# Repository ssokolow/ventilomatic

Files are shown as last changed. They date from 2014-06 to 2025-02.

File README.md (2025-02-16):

# Ventilomatic

A mixture of "course project" and "prototype of a hobby project" intended to
log and regulate the temperature, light level, and humidity in my bedroom.

See the [project site](http://ssokolow.github.io/ventilomatic) for more
details.

## Requirements

* Linux (not yet tested for portability)
* Python 2.x (Python 3.x support will come later)
* [pySerial](http://pyserial.sourceforge.net/) (Will be made optional later)
* [Weatherpy](https://github.com/cmcdowell/weatherpy) (Will be made optional
  later)
* [BottleRocket](http://www.linuxha.com/bottlerocket/) (For X10 control)
* [`libnotify`](http://www.galago-project.org/news/index.php) (For `notify-send`)

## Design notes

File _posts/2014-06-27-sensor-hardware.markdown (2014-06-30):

---
layout: post
title:  "Sensor Hardware"
date:   2014-06-27 01:20:00
categories: design hardware
---

Sorry for the wait (life got **very** distracting and stressful), but here we are. The sensor nodes are done and the Fritzing schematic is in the repository.

**Update:** Incomplete documentation led me to incorrectly believe Pin 10 was free when using the Arduino Ethernet shield. I've relocated the buzzer to pin 8 and updated both the photos and Fritzing files. The originals are available via the git history.

Here are the three different prototype sensor designs:

Arduino Uno + Ethernet Shield
Arduino Leonardo + EtherCard
Sparkfun RedBoard

They all look quite different but, aside from the method of communication (Ethernet shield, EtherCard, and USB serial), they all follow this exact same schematic (Fritzing source files available in the repository, though the non-Breadboard views are a bit of a mess because the DHT22 part for Fritzing is a bit broken):

Fritzing Breadboard View

Sorry about how messy it is. I'm too short on time to find a better way to populate the breadboard and that's the most useful of several ugly options for laying out the Fritzing render.

I haven't yet written the network code, but the draft code for version 1 of the serial interaction model is done (and streams line-by-line JSON in this format):

```json
{ "api_version": 0, "humidity": 56.20, "temperature": 25.10, "dewpoint": 16.34, "light": 295.00 }
```

**Update:** See [Sensing Is A Go]({{ site.baseurl}}{% post_url 2014-06-29-sensing-is-a-go %}) for the updated form the JSON messages take.

Two tips for working on this sort of project:

1. Work with familiar hardware. I don't know what it was, but the Redboard was giving me trouble at first and it was a lot easier to iron out the design and code on my old reliable Arduino Uno (the tallest node pictured), then assemble the design on the Redboard once I was sure that any issues wouldn't be software bugs.
2. Make sure you remember to unplug any other Arduinos before programming. My Uno uses a USB A-B cable while my Leonardo and Redboard use USB A-MiniB and, for a few minutes, I was very frustrated when the serial monitor output wasn't showing changes I'd made to how the board was wired up. Turns out, I was monitoring the wrong Arduino.

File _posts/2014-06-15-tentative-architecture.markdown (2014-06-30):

---
layout: post
title:  "Tentative Architecture"
date:   2014-06-15 08:24:42
categories: design software
---

Here is my first draft for how information will flow in the system's network-transparent design.
(I'll fix the bad kerning once I have a build scripting system in place to make
use of the more complicated commands needed.)

**Update:** At present, due to time constraints, I've had to go for **push-based design** with raw **newline-terminated JSON packets over UDP**. I still hope to switch to a pull-based HTTP design in the future.

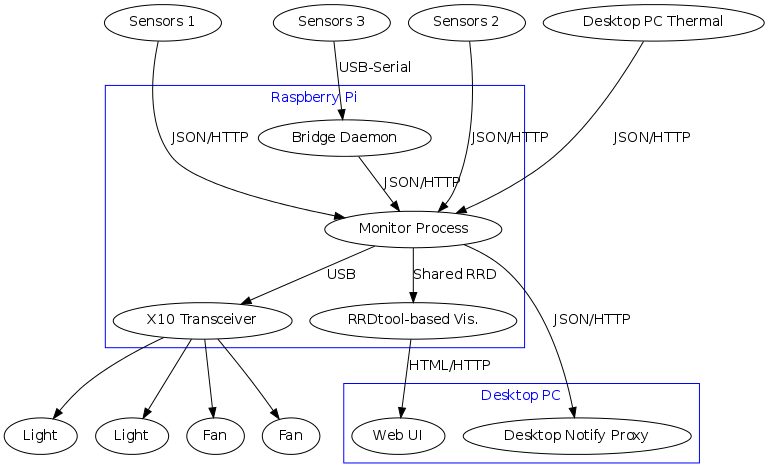
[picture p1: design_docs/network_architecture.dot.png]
Graph Diagram

[[source]({{ site.baseurl}}/design_docs/network_architecture.dot)]

I'm not yet 100% certain that I will use HTTP as the transport for the sensors instead
of UDP but, as the Pythonistas say, premature optimization is the root of all
evil and I definitely want to have JSON-over-HTTP as an option for receiving
sensor data from full-fledged Linux devices.

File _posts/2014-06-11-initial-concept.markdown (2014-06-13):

---
layout: post
title:  "Initial Plans"
date:   2014-06-11 05:43:31
categories: design
---

Well, let's get this project started. This has two purposes:

1. First, it's my course project for [COMP444: Embedded/Robotic Programming](http://www.athabascau.ca/syllabi/comp/comp444.php).

2. More satisfyingly, it's also a chance to prototype a mixture of two
or three ideas that have been rattling around my head and notebook for a while
now.

   Basically, a mixture of an analytics system and pseudo-HVAC controller for
   the temperature, humidity, and light levels in my bedroom.

As I don't yet have the skills to truly produce the design I consider suitable
for permanent installation, this will still have a ways to go, but it should
replicate the function, if not the form, that I desire.

For records purposes, here is the napkin outline I'll be starting from as a
direct quote from the e-mail in which I sent it:

```
1.1. Connect my Arduino Uno, Ethernet Shield, a CdS photoresistor, and
     a "wall wart" power brick.
1.2. Write a simple sketch which allows the sensor to be queried via
     the LAN.
1.3. Attach the photoresistor to the window.

2.1. Connect my Arduino Leonardo, Ethernet Module, a DHT11
     temperature/humidity sensor, and a "wall wart" power brick.
2.2. Again, simple sketch to allow LAN query
2.3. Place the temperature sensor in the family room

3.1. Plug a USB X10 transmitter and Arduino Nano into my Raspberry Pi
3.2. Connect a CdS cell and DHT11 to the Arduino
3.3. Screw my (ugly scrap) alarm system door sensor onto my door frame
     and connect it to the Arduino Nano.
3.3. Write a simple sketch which sends reports to the Raspberry Pi via
     USB serial
3.4. Place the assembly on my desk where it can get a decent
     "baseline room average" reading

4.1. Write a cronjob on the Pi to retrieve sunrise and sunset times and
     exterior temperature and humidity from Yahoo! Weather.
4.2. Write some Python code on the Pi to query and collate all of the
     sensor and Yahoo! weather data and use it for both rrdtool graphs
     and a simple automated light and air quality controller.

Controller goals:
1. Turn the lights off when the sunlight becomes bright enough to
   provide equivalent illumination.
2. Turn the [two independently controlled] fans on and off to control
   humidity in the corner and to exhaust hot summer air into the rest
   of the basement to maintain temperature.
3. If the door is closed, notify the user to open it when air
   circulation is necessary.
4. If the weather forecast says the outdoor air should be a more
   desirable temperature/humidity than the air in the family room,
   notify the user to open the window.
5. If the computer is still in use when the room lighting drops below
   a specified level, turn on a suitable bias light.

(My X10 system already allows me manual control over three light sources,
two fans, a door chime, and an X10 universal module (remote 30V DC relay
and/or sounder, continuous or momentary) which I have yet to find a use for.)

Stretch Goals:
5.1. Write a tool on my desktop PC which feeds in the screensaver
     subsystem's idleness data for information about
     user presence and activity to inform decision-making.
5.2. Extend the tool to listen to output from the "motion" utility
     to detect user presence when away from keyboard via the webcam.
```

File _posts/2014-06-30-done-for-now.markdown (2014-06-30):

---
layout: post
title:  "Done (For Now)"
date:   2014-06-30 03:45:00
categories: status
---
I have some stuff to finish up in another course, so I seriously doubt I'll be able to work on this any more before the end of today. As such, this is the final state the project will take before my course deadline.

# Results

Given the time-crunch, I definitely had to make some compromises. (For example, I'm currently running the control node on my desktop PC because it already has the CM17A set up for sending X10 messages but I used that as a blocking operation. While fast reactions may not be essential in this application, I'll still want to switch to an asynchronous design if for no other reason than making absolutely sure it's impossible for the UDP receive buffers to overflow and start losing measurements I want to log and graph.)

I also noticed that the voltage regulator on my Arduino Uno is dissipating a lot more heat than would seem reasonable when powered by [my 9V supply]({{ site.baseurl }}/img/parts/psu_2.jpg) so that's something else I'll have to investigate before producing versions for permanent installation.

However, given my goals, the obstacles I faced, and the time I had, I think I did pretty well for a first sprint. Here is an overview of the status of the "end result" goals as of my course's contract date:

### Controller Goal #1: DONE
*Turn the lights off when the sunlight becomes bright enough to
   provide equivalent illumination.*

I don't have time to properly calibrate it before my contract date, but the light sensor on the `corner` node (the one on an extension and taped to the window) will currently trigger a shut-down of all three X10-controllable lights in the room when it detects a high enough reading.

All I have to do is open the window, reach out with my high-intensity LED flashlight, and `*CLACK* ... *CLACK* ... *CLACK*`, all of the X10-controllable lights in the room turn off.

### Controller Goal #2: PARTIAL
*Turn the [two independently controlled] fans on and off to control humidity in the corner and to exhaust hot summer air into the rest of the basement to maintain temperature.*

I've implemented the rule for dealing with humidity in the corner, but the temperature part requires a sensor outside my room and I didn't have time to get the EtherCard stuff written and debugged.

### Controller Goal #3: FOILED
*If the door is closed, notify the user to open it when circulation is necessary.*

I looked everywhere and can't figure out where I stashed my magnetic reed switch. I've ordered a new five-pack, but they won't be here before my contract date. However, I *can* write master controller code for when the hardware *does* get added to one of the sensor nodes and I can write it in such a way that it assumed a missing sensor means "door closed" so it'll always ask me.

### Controller Goal #4: DONE
*If the weather forecast says the outdoor air should be a more desirable temperature/humidity than the air in the family room, notify the user to open the window.*

The system queries Yahoo! Weather once an hour to get the outside temperature and, if the desired temperature is closer to that than the indoor air temperature, it uses `notify-send` to suggest opening a window.

### Controller Goal #5: MISSED
*If the computer is still in use when the room lighting drops below a specified level, turn on a suitable bias light.*

I ran out of time before I could write the daemon to feed readings from the screensaver's idleness API into the system. As such, it has no way to detect "If the computer is still in use when..."

I'll try to make time to write this within the first week of July.

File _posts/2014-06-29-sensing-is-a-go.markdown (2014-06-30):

---
layout: post
title:  "Sensing Is A Go"
date:   2014-06-29 23:38:00
categories: design hardware software
---

Well, a lack of time has necessitated some corner-cutting, but basic network support is now working. I've got two sensors (one serial and one ethernet) and a basic `main.py` which listens to them.

```python
{u'temperature': 27.4, u'dewpoint': 19.02, u'light': 289.0, u'humidity': 58.1, u'node_id': u'desktop', u'api_version': 0}
{u'temperature': 29.0, u'dewpoint': 20.6, u'light': 274.0, u'humidity': 58.0, u'node_id': u'corner', u'api_version': 0}
{u'temperature': 27.4, u'dewpoint': 19.02, u'light': 273.0, u'humidity': 58.1, u'node_id': u'desktop', u'api_version': 0}
{u'temperature': 29.0, u'dewpoint': 20.6, u'light': 286.0, u'humidity': 58.0, u'node_id': u'corner', u'api_version': 0}
{u'temperature': 27.4, u'dewpoint': 19.02, u'light': 284.0, u'humidity': 58.1, u'node_id': u'desktop', u'api_version': 0}
{u'temperature': 29.0, u'dewpoint': 20.6, u'light': 289.0, u'humidity': 58.0, u'node_id': u'corner', u'api_version': 0}

```

(Eagle-eyed readers may notice that's not valid JSON. It's Python `repr()` debugging output which indicates that `main.py` successfully received, defragmented, and parsed valid JSON, then confirmed the correct value for the `api_version` field.)

Arduino coders who've worked with the WizNet Ethernet shield before may also notice that I'm not using the SD card library yet the shield remains reliable. For anyone who's wondering, the answer is to explcitly disable the SD card reader so it doesn't confuse the SPI bus by trying to talk at the same time as the Ethernet chip.

```c++
    // Source: http://forum.freetronics.com/viewtopic.php?f=4&t=176&start=50
    pinMode(53, OUTPUT);   // set the SS pin as an output (necessary on Mega2560?)
    digitalWrite(53, LOW); // ? (not sure)
    pinMode(4,  OUTPUT);   // SD select pin             (required)
    digitalWrite(4, HIGH); // Explicitly disable SD     (required)
    pinMode(10, OUTPUT);   // Ethernet select pin       (optional?)
    digitalWrite(10, LOW); // Explicitly enable Network (optional?)
```

The same principle applies in reverse if you want to use the SD card without the Ethernet. (If you're using both, the libraries handle everything for you)

### Caveats

At the moment, the sensors still have a single point of failure in that their communication is a blocking operation, so a dead serial or network link will prevent the internal alarm from going off. I doubt I'll have time to fix that before my course contract date so the dewpoint alarm will have to be purely for alerting when the network or serial link is up but there's a failure between `main.py` and whatever notification GUI I've configured.

I'm still having trouble with the third sensor (the one using the cheap ENC28J60-based network module) but that could be a driver issue since it's failing on the DHCP request. 

### From Here...

Aside from trying the ENC28J60 module with hard-coded IP settings, I don't expect I'll be doing any more work in the Arduino IDE before my contract date.

Given that my hardware is very heterogeneous, I never had time to set up EEPROM storage of the MAC address and node ID, and I don't know how to use Makefiles with Arduino, I specifically designed this project so that I could get the nodes programmed and the IDE closed as soon as possible. Making sure I've flashed each Arduino with the right config constants is just too much hassle to keep doing.

That means that, aside from getting that last node configured, everything else before the contract date will either be master node coding or simple hardware adjustments (like pulling the Light-Dependent Resistor from the corner sensor and sticking it on the end of a length of twisted pair wire so I can tape it to the window.

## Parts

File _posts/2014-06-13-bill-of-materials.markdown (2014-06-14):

---
layout: post
title:  "Bill of Materials"
date:   2014-06-13 12:23:35
categories: design hardware
---

OK, let's start with the hardware design.

The system will involve three sensor modules and one central controller module
interconnected by the existing house LAN and some pre-existing X10 home
automation gear.

To keep the designs as simple as possible, all three sensors will share these
characteristics:

* One [DHTxx-family temperature/humidity sensor](https://learn.adafruit.com/dht/overview)
* One [cadmium sulphide photoresistor](https://en.wikipedia.org/wiki/Photoresistor)
* One buzzer for warning of [condensation-inducing](https://en.wikipedia.org/wiki/Dew_point)
  conditions without relying on the complex, failure-prone signalling path
  through the normal LAN-based reporting interface.

However, as this is being prototyped from supplies I already have, I'm going to
need to build three heterogeneous sensors.

**Note:** As I don't regularly assemble these things from memory, this list may
be revised as I actually do the assembly work.

## Sensor #1

This sensor gets first pick of the components, so it gets all the ones that are
easiest to work with and/or least overkill spec-wise.

* 1 x [Arduino Uno]({{ site.baseurl }}img/parts/arduino_uno.jpg) or compatible ([~$11 CDN](http://www.dx.com/p/development-board-w-data-cable-for-arduino-uno-r3-deep-blue-cable-52cm-312887))
* 1 x [Arduino Ethernet Shield]({{ site.baseurl }}img/parts/ethernet_shield.jpg) ([~$9 CDN](http://www.ebay.ca/sch/i.html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))
* 1 x [Arduino Prototyping Shield]({{ site.baseurl }}img/parts/prototyping_shield.jpg) ([~$4 CDN](http://www.ebay.ca/sch/i.html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))
* 1 x [Set of stacking headers]({{ site.baseurl }}img/parts/stacking_headers.jpg) (to allow the Protoshield to clear the RJ45
  connector, [~$3 CDN](http://www.ebay.ca/sch/i.html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) if not bought in volume)
* 1 x [DHT11 temperature/humidity sensor]({{ site.baseurl }}img/parts/dht11.jpg) ([~$1.50 CDN](http://www.ebay.ca/sch/i.html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))
* 1 x [CdS photoresistor]({{ site.baseurl }}img/parts/cds_cell.jpg) ([5.5¢ ea.](http://www.ebay.ca/sch/i.html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) in a 20-pack)
* 1 x [5V magnetic buzzer]({{ site.baseurl }}img/parts/buzzer.jpg) ([$1.5 CDN for 5 or $1.75 CDN for 10](http://www.ebay.ca/sch/i.html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))
* 1 x [breadboard hookup wire kit]({{ site.baseurl }}img/parts/hookup_wire.jpg) ([~$3.50 CDN](http://www.ebay.ca/sch/i.html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) shared across the whole project)
* 1 x [12VDC 1A power supply]({{ site.baseurl }}img/parts/psu_1.jpg)
* 1 x [Cat-5 Ethernet patch cable]({{ site.baseurl }}img/parts/cat5_patch.jpg)

...plus standoffs to keep it from electrically contacting the floor since this
is the sensor which will be used where condensation is a concern.

(Specifically, [three 10mm hexagonal female-female standoffs]({{ site.baseurl }}img/parts/3_standoffs.jpg) to act as legs and
one stacked pair of shorter [male-female standoffs and a twist-tie]({{ site.baseurl }}img/parts/m-f_spacers.jpg) for the
remaining mounting hole since I lack a machine screw with a head small enough
to fit nicely next to the SCL header on the Arduino revision 3 layout.)

## Sensor #2

This sensor gets the remaining network-capable components.

* 1 x [Freaduino Leonardo]({{ site.baseurl }}img/parts/freaduino_leonardo.jpg) or compatible ([~$13 CDN](http://www.dx.com/p/diy-eduino-leonardo-module-blue-black-213956))
* 1 x [ENC28J60 Ethernet Module]({{ site.baseurl }}img/parts/enc28j60_module.jpg) ([~$4 CDN](http://www.ebay.ca/sch/i.html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))
* 1 x [Arduino Prototyping Shield]({{ site.baseurl }}img/parts/prototyping_shield.jpg) ([~$4 CDN](http://www.ebay.ca/sch/i.html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))
* 1 x [DHT11 temperature/humidity sensor]({{ site.baseurl }}img/parts/dht11.jpg) ([~$1.50 CDN](http://www.ebay.ca/sch/i.html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))
* 1 x [CdS photoresistor]({{ site.baseurl }}img/parts/cds_cell.jpg) ([5.5¢ ea.](http://www.ebay.ca/sch/i.html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) in a 20-pack)
* 1 x [5V magnetic buzzer]({{ site.baseurl }}img/parts/buzzer.jpg) ([$1.5 CDN for 5 or $1.75 CDN for 10](http://www.ebay.ca/sch/i.html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))
* 1 x [breadboard hookup wire kit]({{ site.baseurl }}img/parts/hookup_wire.jpg) ([~$3.50 CDN](http://www.ebay.ca/sch/i.html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) shared across the whole project)
* 1 x [9VDC 500mA power supply]({{ site.baseurl }}img/parts/psu_2.jpg)
* 10 ft. Category 3 telephone wire
* 1 x [Cat-5 Ethernet patch cable]({{ site.baseurl }}img/parts/cat5_patch.jpg)

The telephone wire is necessary for running the floor humidity and window light
level sensors off the same node due to a shortage of Ethernet modules.

No standoffs are necessary for this sensor since it will be resting on an
unfinished wooden surface.

## Sensor #3

With no network adaptor modules left, this sensor connects to the central
controller directly via the USB serial interface. Also, having run out of DHT11
sensors, this one uses a more precise but more expensive DHT22 instead.

* 1 x [SparkFun Redboard]({{ site.baseurl }}img/parts/redboard.jpg) or compatible ([~$11 CDN](http://www.dx.com/p/development-board-w-data-cable-for-arduino-uno-r3-deep-blue-cable-52cm-312887))
* 1 x [Solderless Breadboard]({{ site.baseurl }}img/parts/breadboard.jpg)
* 1 x [DHT22 temperature/humidity sensor]({{ site.baseurl }}img/parts/dht22.jpg) ([$4.50 CDN](http://www.ebay.ca/sch/i.html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))
* 1 x [CdS photoresistor]({{ site.baseurl }}img/parts/cds_cell.jpg) ([5.5¢ ea.](http://www.ebay.ca/sch/i.html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) in a 20-pack)
* 1 x [5V magnetic buzzer]({{ site.baseurl }}img/parts/buzzer.jpg) ([$1.5 CDN for 5 or $1.75 CDN for 10](http://www.ebay.ca/sch/i.html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))
* 1 x [breadboard hookup wire kit]({{ site.baseurl }}img/parts/hookup_wire.jpg) ([~$3.50 CDN](http://www.ebay.ca/sch/i.html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) shared across the whole project)
* 1 x Normally open, door-mountable magnetic switch
* 12 ft. Category 3 telephone wire
* 1 x [12VDC 1A power supply]({{ site.baseurl }}img/parts/psu_3.jpg)
* 1 x [Short USB A-to-MiniB cable]({{ site.baseurl }}img/parts/short_usb_mini.jpg)

This sensor node will have the additional task of monitoring whether the door
needs to be manually opened to allow the fan on X10 channel 4 to have the
desired effect.

While the power supply isn't strictly necessary, the Raspberry Pi is known for
having a tendency to corrupt SD cards when supplied with insufficent power and
I don't currently have the tools and skill to determine whether that's a
concern in this configuration.

No standoffs are necessary for this sensor since it will be resting on an
unfinished wooden surface.

## Central Controller

* 1 x [Raspberry Pi]({{ site.baseurl }}img/parts/raspberry_pi.jpg)
* 1 x [5V 1A USB Micro cellphone charger]({{ site.baseurl }}img/parts/psu_raspi.jpg)
* 1 x [SD Card]({{ site.baseurl }}img/parts/sd_card.jpg)
* 1 x [CM19A USB X10 transceiver]({{ site.baseurl }}img/parts/cm19a.jpg) ([$20-30 US](http://www.thehomeautomationstore.com/cm19a.html))
* 1 x [Cat-5 Ethernet patch cable]({{ site.baseurl }}img/parts/cat5_patch.jpg)

**Note:** Depending on how this project turns out, I may end up either using a
[CM17A](http://www.ebay.ca/sch/i.html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) with a USB-Serial adapter or just using my planned network-transparent architecture to
pipe X10 control commands to my desktop PC which already has an X10 transceiver connected.

After all, I'll probably be running a system node on my desktop anyway to log
its internal thermal sensors and the CM17A is easier to work with on the
software side... it just requires an RS-232 serial port and is very picky about
which cheap Chinese USB-Serial adapters it will get along with.

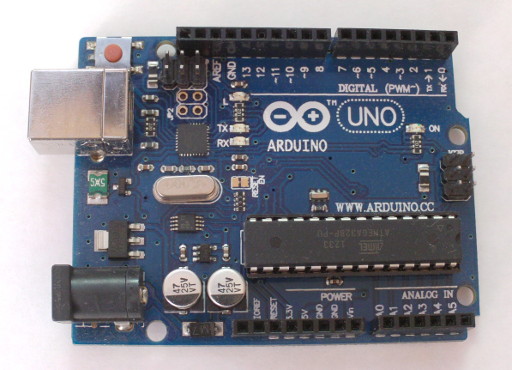
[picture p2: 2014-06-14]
img/parts/arduino_uno.jpg

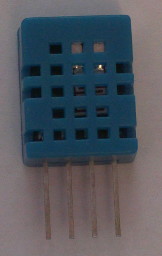
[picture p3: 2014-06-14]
img/parts/dht11.jpg

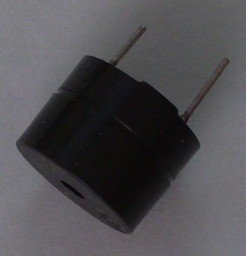
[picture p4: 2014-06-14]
img/parts/buzzer.jpg

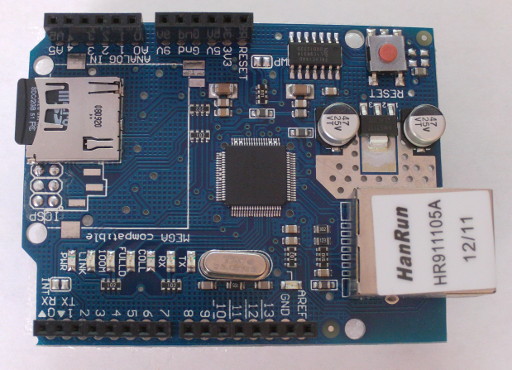
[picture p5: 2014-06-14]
img/parts/ethernet_shield.jpg

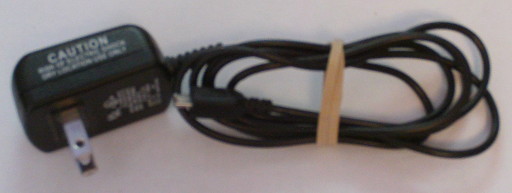
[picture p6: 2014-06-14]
img/parts/psu_raspi.jpg

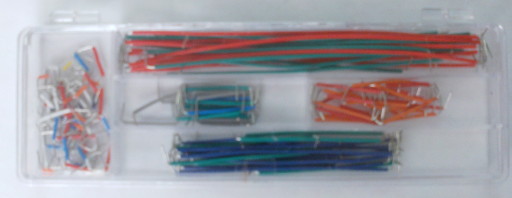
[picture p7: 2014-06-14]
img/parts/hookup_wire.jpg

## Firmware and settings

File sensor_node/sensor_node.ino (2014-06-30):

/* Sensor Node for Ventilomatic
By: Stephan Sokolow

License: GNU GPL 2.0 or later

Note: You are expected to already have one or both of the following
      libraries installed in your Arduino IDE, depending on the
      hardware you intend to program with this sketch:
- https://github.com/adafruit/DHT-sensor-library
- https://github.com/jcw/ethercard

Hungarian Notation Prefixes:
- AP: Analog Pin
- AV: Analog Value (from analogRead)
- C: Constant (The value is one of several constants like DHT11)
- DP: Digtal Pin
- DV: Digital Value (from digitalRead)
- SP: Status Packet (Serial, UDP, etc.)
- T: Temperature (Celsius)
- H: Humidity (Percent)
*/

/* --== Select how the node will report to the master ==-- */
#define SERIAL 0     // Built-in USB-Serial bridge
#define ETHERNET 1   // WizNet Ethernet Shield

#define MODE SERIAL
//#define MODE ETHERNET

/* --== Configure network communication ==-- */

// These must be different for each node
//const char NODE_ID[] = "corner";
//byte MAC_ADDR[] = { 0xDF, 0x5E, 0x64, 0xD1, 0x8F, 0xBA };
//const char NODE_ID[] = "family_room";
//byte MAC_ADDR[] = { 0xDF, 0x5E, 0x64, 0xD1, 0x8F, 0xBB };
const char NODE_ID[] = "desktop";
byte MAC_ADDR[] = { 0xDF, 0x5E, 0x64, 0xD1, 0x8F, 0xBC };

// This must be the same for all nodes
const byte MASTER_NODE[] = { 192, 168, 0, 2 };
const unsigned short UDP_PORT = 51199;

/* --== Configure the hardware ==-- */

#define AP_LDRPIN 0 // Analog pin
#define DP_ALARMPIN 8

// Temperature sensor configuration
#define DP_DHTPIN 3
#define C_DHTTYPE DHT11
//#define C_DHTTYPE DHT22

/* --== Main Program Starts Here ==-- */

/* -- Code to abstract away communications -- */
// Define Serial writing routines
#if MODE == SERIAL
#define SP_WRITE(x) Serial.print(x)
void sp_begin(char header[]) { SP_WRITE(header); }
void sp_end(char footer[]) { Serial.println(footer); }

// Import WizNet library and define writing routines
#elif MODE == ETHERNET
#include <SPI.h>         // needed for Arduino versions later than 0018
#include <Ethernet.h>
#include <EthernetUdp.h>         // UDP library from: bjoern@cs.stanford.edu 12/30/2008

EthernetUDP udp;
const IPAddress IP_MASTER_NODE(MASTER_NODE[0], MASTER_NODE[1],
                               MASTER_NODE[2], MASTER_NODE[3]);

#define SP_WRITE(x) udp.print(x)
void sp_begin(char header[]) {
  // TODO: Will anything bad happen if I don't do this and the
  //       receive buffer fills up?
  udp.parsePacket();

  udp.beginPacket(IP_MASTER_NODE, UDP_PORT);
  SP_WRITE(header);
}
void sp_end(char footer[]) {
  SP_WRITE(footer);
  SP_WRITE("\n");
  udp.endPacket();
}
#endif

/* -- Code for generating status packets -- */

/** Wrapper for printing all but the first JSON key/value pair
    (floating point values) */
void json_print_if(const char key[], float val) {
  SP_WRITE(", \"");
  SP_WRITE(key);
  SP_WRITE("\": ");
  if (isnan(val)) {
    SP_WRITE("null");
  } else {

    SP_WRITE(val);
  }
}

/** Wrapper for printing all but the first JSON key/value pair
    (string values)

    @bug: This does not escape quotes **/
void json_print_if(const char key[], const char val[]) {
  SP_WRITE(", \"");
  SP_WRITE(key);
  SP_WRITE("\": \"");
  SP_WRITE(val);
  SP_WRITE("\"");
}

/* -- Common code to actually drive the node -- */

#include "DHT.h"
DHT dht(DP_DHTPIN, C_DHTTYPE);

boolean is_alarming = 0;

void setup() {
  pinMode(DP_ALARMPIN, OUTPUT);
  digitalWrite(DP_ALARMPIN, HIGH);

#if MODE == SERIAL
  Serial.begin(9600);
#elif MODE == ETHERNET
  // Make the Ethernet shield reliable without the SD card library
  pinMode(4,  OUTPUT);   // SD select pin             (required)
  digitalWrite(4, HIGH); // Explicitly disable SD     (required)

  while (Ethernet.begin(MAC_ADDR) == 0) {
    // ...if DHCP request failed, wait one minute, then retry
    delay(1000 * 60);
  }

  // Needed even if we don't intend to receive any packets
  udp.begin(UDP_PORT);
#else
#error Unrecognized Communication Mode
#endif
}

void loop() {
  float h_relative = dht.readHumidity();
  float t_ambient = dht.readTemperature();
  float av_light = analogRead(AP_LDRPIN);
  boolean dv_alarmpin = digitalRead(DP_ALARMPIN);
  
  // Calculate a simple approximation of the dewpoint
  // (accurate above 58% humidity) to control the alarm
  // independently of the master control node.
  // Source: https://en.wikipedia.org/wiki/Dewpoint
  float t_dewpoint = t_ambient - ((100 - h_relative) / 5);
  is_alarming = t_ambient < t_dewpoint;
  
  // Use the DHT's read delay as an alarm timing source
  dv_alarmpin = (is_alarming && dv_alarmpin == HIGH) ? LOW : HIGH;
  digitalWrite(DP_ALARMPIN, dv_alarmpin);

  // Output in JSON
  sp_begin("{ \"api_version\": 0");
  json_print_if("node_id", NODE_ID);
  json_print_if("humidity", h_relative);
  json_print_if("temperature", t_ambient);
  json_print_if("dewpoint", t_dewpoint);
  json_print_if("light", av_light);
  sp_end(" }");
}

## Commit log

2014-06-13 Add the initial text for the bill of materials.
2014-06-14 Add photos for most of the items on the bill of materials
    (Taken myself since the ability to use the same license as the rest of the
    project is more important than perfect picture quality.)
2014-06-14 Polish up the landing page and layout a bit before pushing it public.
2014-06-27 Create blank Arduino project for sensor node firmware.
2014-06-27 Add code to read from the light-dependant resistor.
2014-06-27 Add code to drive the alarm beeper.
    (Currently hard-coded to off, but testable by editing `is_alarming = 0`
    and recompiling.)
2014-06-27 Hook is_alarming up to a simple approximation of the dewpoint formula.
    This allows each node to have a direct, robust means to warn of conditions
    that produce condensation and promote the growth of mould.
    (Source: https://en.wikipedia.org/wiki/Dewpoint#Simple_approximation)
2014-06-27 Switch output format to JSON in preparation for machine consumption.
2014-06-27 Switch to more helpful variable names
2014-06-27 Forgot pin 11 was used by the SPI bus. Move alarm to pin 10.
2014-06-27 Add a blog post with pictures and Fritzing diagram for sensor nodes.
    [sensor_node.fzz]
2014-06-30 How did I forget to include a proper header in sensor_node.ino
2014-06-30 Whoops. Move the sounder to pin 8.
    (I was operating from an incomplete chart and didn't notice that Pin 10
    was also used by the Ethernet shield.)
    [sensor_node.fzz]
2014-06-30 Add a "node_id" JSON parameter so the master need not track packet source
2014-06-30 Implement support for communication via the Arduino Ethernet Shield
    (Uses explicit SD card slot disabling trick from
    http://forum.freetronics.com/viewtopic.php?f=4&t=176&start=50 to make
    Ethernet shield operate reliably without the SD card library loaded.)
2014-06-30 Start gearing up to integrate Yahoo! Weather into the rules system.
    - Add a requirements.txt
    - List system requirements in README.md
    - Add a TODO list
2014-06-30 Add a fan-controller rule to prevent the corner from getting musty
2014-06-30 Throttle rule evaluation and give time for the model to form first
